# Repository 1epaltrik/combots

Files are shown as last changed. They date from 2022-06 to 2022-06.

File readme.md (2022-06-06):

<p style="text-align: center;"><h1> Έξυπνο σύστημα κομποστοποίησης </h1></p>
<br>
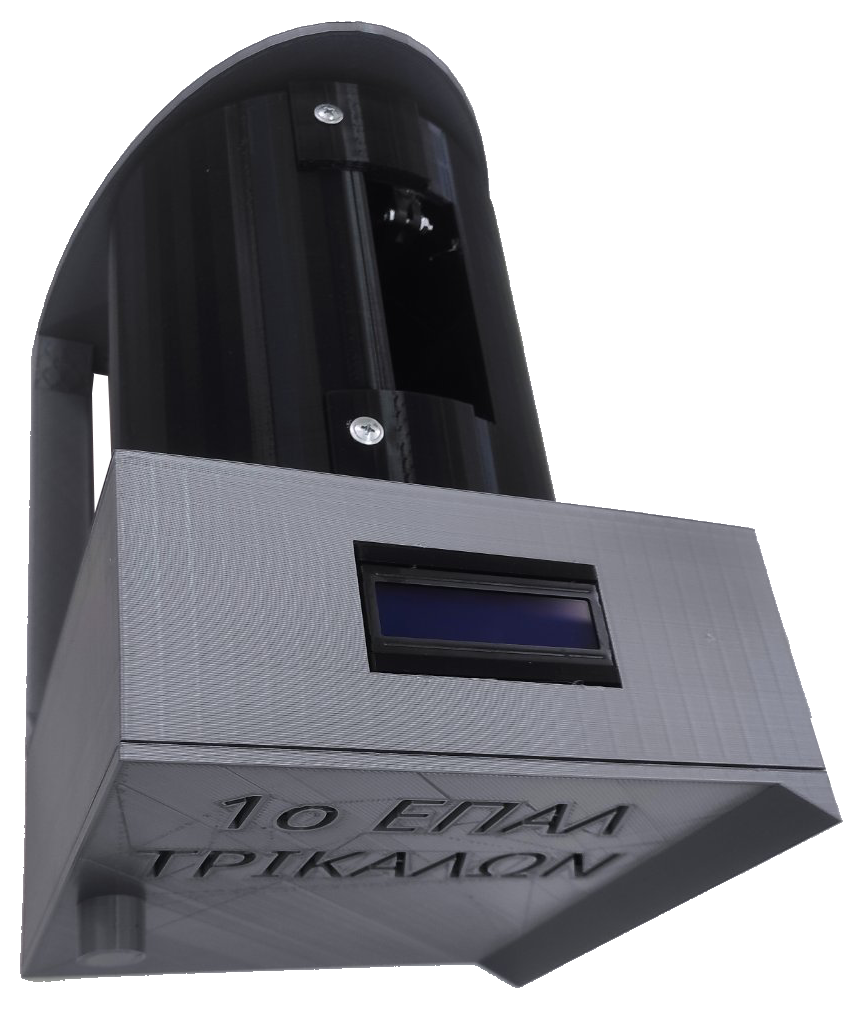
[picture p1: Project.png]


<p style="text-align: justify;">Είμαστε η ομάδα ComBots από το 1ο ΕΠΑΛ Τρικάλων.</p>
<p style="text-align: justify;">Αρχικά μελετήσαμε την υπάρχουσα κατάσταση γύρω από την κομποστοποίηση αντλώντας πληροφορίες κυρίως από το διαδίκτυο αλλά και από βιβλία. Διαπιστώσαμε ότι ένα σύστημα κομποστοποίησης μπορεί να ελαχιστοποιήσει ή και να μηδενίσει τα απόβλητα σε όλα τα στάδια παραγωγής, αλλά και μετά το τέλος του κύκλου ζωής των προϊόντων. Βασική επιδίωξη είναι η ενθάρρυνση χρήσης δευτερογενών υλικών και αποβλήτων ως παραγωγικών πόρων και χρήσιμων υλικών προσδίδοντας τη διάσταση της βιωσιμότητας στο παραγωγικό μοντέλο.</p>
<p style="text-align: justify;">Πριν ξεκινήσουμε την υλοποίηση του έργου ασχοληθήκαμε με τις αρχές και τις πρακτικές της Επιστήμης των Πολιτών. Από τη στιγμή που έπεσε η ιδέα της κομποστοποίησης κάναμε την έρευνα που αναφέραμε και δημιουργήσαμε ένα ερωτηματολόγιο σχετικό με την κυκλική οικονομία και την κομποστοποίηση για τη συμπεριφορά και τις απόψεις μαθητών και πολιτών της πόλης μας. Σημαντικότερα αποτελέσματα που εξάγουμε από το ερωτηματολόγιό αναφέρονται στο βίντεο που ακολουθεί.</p>
<p style="text-align: justify;">Η κομποστοποίηση αποτελεί ένα μέρος της Κυκλικής Οικονομίας και βοηθάει στην αντιμετώπιση του φαινομένου της  Κλιματικής Αλλαγής. Η ενθάρρυνση χρήσης συστημάτων κομποστοποίησης από κοινότητες, Δήμους, Περιφέρειες, Ιδιωτικούς Φορείς και γενικότερα των πολιτών κρίνεται απαραίτητη, ειδικά στην εποχή που διανύουμε.</p>
<p style="text-align: justify;">Δημιουργήσαμε ένα Έξυπνο σύστημα κομποστοποίησης, το οποίο μέσω αισθητήρων θα καταγράφει στο εσωτερικό του:</p>

<ol style="text-align: justify;">
 	<li>Υγρασία μείγματος κομπόστ</li>
 	<li>Υγρασία αέρα</li>
 	<li>Θερμοκρασία αέρα</li>
 	<li>Επίπεδα μεθανίου</li>
</ol>
<p style="text-align: justify;">Ανάλογα με τις τιμές ενεργοποιείται ένα σύστημα αερισμού, ένα σύστημα αύξησης της υγρασίας στο εσωτερικό και ένα μοτέρ που μετακινεί το περιεχόμενο του κάδου κομποστοποίησης. Όλες αυτές οι τιμές εμφανίζονται στην οθόνη που υπάρχει στην κατασκευή μας.</p>
<p style="text-align: justify;">Αντίστοιχο σύστημα έξυπνης κομποστοποίησης δεν βρήκαμε ούτε στην ελληνική, ούτε στην ξένη αγορά. Για την υλοποίησή του χρησιμοποιήσαμε Ανοιχτές Τεχνολογίες μέσω μιας διάταξης Arduino, το Διαδίκτυο των πραγμάτων και τρισδιάστατη εκτύπωση.</p>
<p style="text-align: justify;">Τα υλικά που χρησιμοποιήσαμε ήταν:</p>

<ul style="text-align: justify;">
 	<li>Ένα Funduino Mega2560</li>
 	<li>Ένα Breadboard</li>
 	<li>Μία Οθόνη LCD - RGB Ι2C</li>
 	<li>Έναν αισθητήρα Θερμοκρασίας/Υγρασίας/Βαρομετρικής Πίεσης I2C BME280</li>
 	<li>Έναν αισθητήρα Μεθανίου CNG - MQ-4</li>
 	<li>Ένα Relay 2 θέσεων</li>
 	<li>Μία αντλία νερού</li>
 	<li>Έναν ανεμιστήρα</li>
 	<li>Έναν βηματικό Κινητήρα 4.5kg με Οδηγό A4988</li>
 	<li>Καλώδια για τη διασύνδεση όλων αυτών και</li>
 	<li>Νήμα για την τρισδιάστατη εκτύπωση</li>
</ul>
<p style="text-align: justify;">Το κόστος όλων αυτών ανήλθε στα €150.</p>
<p style="text-align: justify;">H σχεδίαση του κυκλώματος έγινε λαμβάνοντας υπόψη όσα ανακαλύφθηκαν από την έρευνα που πραγματοποιήσαμε. Στην αρχή είδαμε τον κάθε αισθητήρα και σύστημα ενεργοποίησης, αλλά στο τέλος τα συνθέσαμε όλα μαζί. Η έρευνά μας, τα σχέδια των κυκλωμάτων και ο κώδικας για την υλοποίηση του έργου μας είναι διαθέσιμα στο github (<a href="https://github.com/1epaltrik/combots">https://github.com/1epaltrik/combots</a>).</p>
<p style="text-align: left;">Tο βίντεο με την παρουσίαση του έργου, από την αρχή μέχρι και την ολοκλήρωσή του θα το βρείτε στην ιστοσελίδα <a href="https://youtu.be/cvGBoXvN4oI">https://youtu.be/cvGBoXvN4oI</a></p>
<p style="text-align: justify;">Στόχος μας μετά τον διαγωνισμό είναι να παρουσιάσουμε την ιδέα μας στον Δήμο που κατοικούμε, προτείνοντας να τοποθετηθούν στην πόλη κάδοι κομποστοποίησης μεγαλύτερης κλίμακας που θα χρησιμοποιούν τις τεχνολογίες που ανακαλύψαμε για τη συμβολή της έξυπνης πόλης μας στην κυκλική οικονομία.</p>
&nbsp;

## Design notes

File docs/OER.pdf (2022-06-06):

## Έξυπνο σύστημα κομποστοποίησης 1ο ΕΠΑΛ Τρικάλων

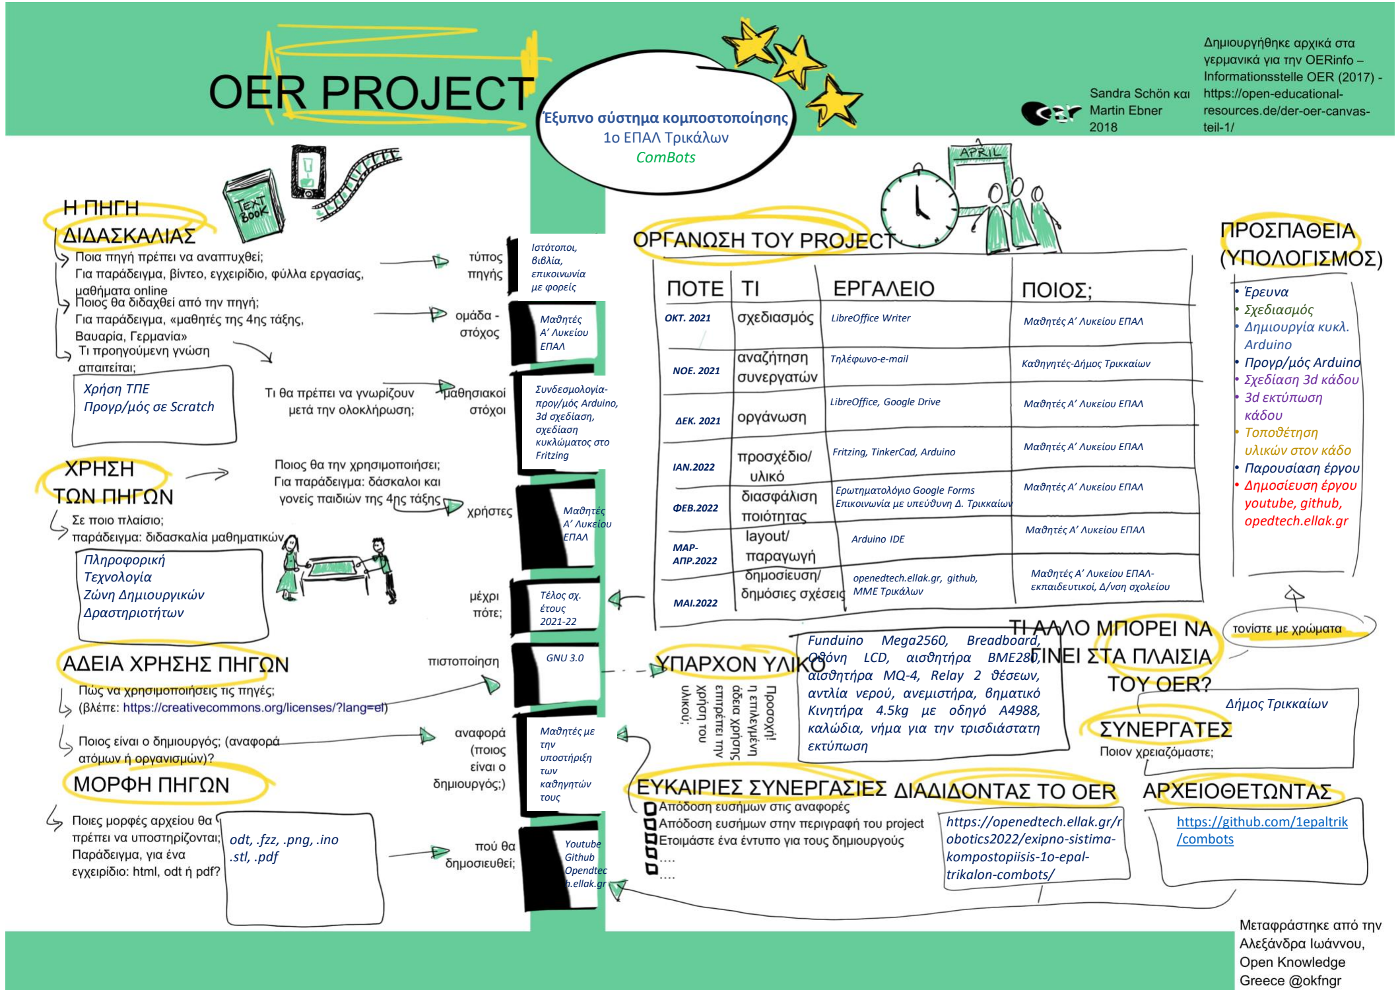
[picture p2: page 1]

## Χρήση ΤΠΕ Προγρ/μός σε Scratch

## Πληροφορική Τεχνολογία Ζώνη Δημιουργικών Δραστηριοτήτων

## odt, .fzz, .png, .ino .stl, .pdf

## https://openedtech.ellak.gr/r obotics2022/exipno-sistimakompostopiisis-1o-epaltrikalon-combots/

## https://github.com/1epaltrik /combots (https://github.com/1epaltrik/combots)

## Δήμος Τρικκαίων

## - Έρευνα - Σχεδιασμός

- Δημιουργία κυκλ.

## Arduino - Προγρ/μός Arduino - Σχεδίαση 3d κάδου - 3d εκτύπωση κάδου - Τοποθέτηση υλικών στον κάδο - Παρουσίαση έργου - Δημοσίευση έργου

youtube, github,

## opedtech.ellak.gr

## ComBots

Ιστότοποι,
βιβλία,
επικοινωνία
με φορείς

Μαθητές
Α’ Λυκείου
ΕΠΑΛ

Συνδεσμολογίαπρογ/μός Arduino,
3d σχεδίαση,
σχεδίαση
κυκλώματος στο
Fritzing

Μαθητές
Α’ Λυκείου
ΕΠΑΛ

Τέλος σχ.
έτους
2021-22

GNU 3.0

Μαθητές με
την
υποστήριξη
των
καθηγητών
τους

Youtube
Github
Opendtec
h.ellak.gr
Funduino | Mega2560, | Breadboard,
Οθόνη LCD, αισθητήρα BME280, αισθητήρα MQ-4, Relay 2 θέσεων,

## αντλία νερού, ανεμιστήρα, βηματικό

Κινητήρα 4.5kg με oδηγό A4988,

## καλώδια, νήμα για την τρισδιάστατη εκτύπωση

ΟΚΤ. 2021 | LibreOffice Writer

ΝΟΕ. 2021

ΔΕΚ. 2021

ΙΑΝ.2022

ΦΕΒ.2022

ΜΑΡ-ΑΠΡ.2022

ΜΑΙ.2022

Μαθητές Α’ Λυκείου ΕΠΑΛ

Fritzing, TinkerCad, Arduino

Τηλέφωνο-e-mail | Καθηγητές-Δήμος Τρικκαίων

Μαθητές Α’ Λυκείου ΕΠΑΛ

Μαθητές Α’ Λυκείου ΕΠΑΛ

Μαθητές Α’ Λυκείου ΕΠΑΛ

Μαθητές Α’ Λυκείου ΕΠΑΛ

Μαθητές Α’ Λυκείου ΕΠΑΛεκπαιδευτικοί, Δ/νση σχολείου

Arduino IDE

Ερωτηματολόγιο Google Forms Επικοινωνία με υπεύθυνη Δ. Τρικκαίων

LibreOffice, Google Drive

openedtech.ellak.gr, github, ΜΜΕ Τρικάλων

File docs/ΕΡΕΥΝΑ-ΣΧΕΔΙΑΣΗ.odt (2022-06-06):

Έρευνα

Σημαντικές έννοιες

Κυκλική οικονομία είναι η επιμήκυνση του κύκλου ζωής των προϊόντων, με παράλληλη εξοικονόμηση μη ανανεώσιμων φυσικών πόρων, μέσω της μείωσης, επαναχρησιμοποίησης, ανακύκλωσης και ανάκτησης πρώτων υλών, ενέργειας και αποβλήτων.

Η κομποστοποίηση είναι μια φυσική διαδικασία η οποία μετατρέπει τα οργανικά υλικά σε μια πλούσια σκούρα ουσία. Αυτή η ουσία λέγεται κομπόστ ή χούμους ή εδαφοβελτιωτικό. Η κομποστοποίηση είναι ένας πολύ άμεσος και σημαντικός τρόπος ανακύκλωσης. Έχει υπολογιστεί ότι το 35% των οικιακών απορριμμάτων μπορούν να κομποστοποιηθούν.

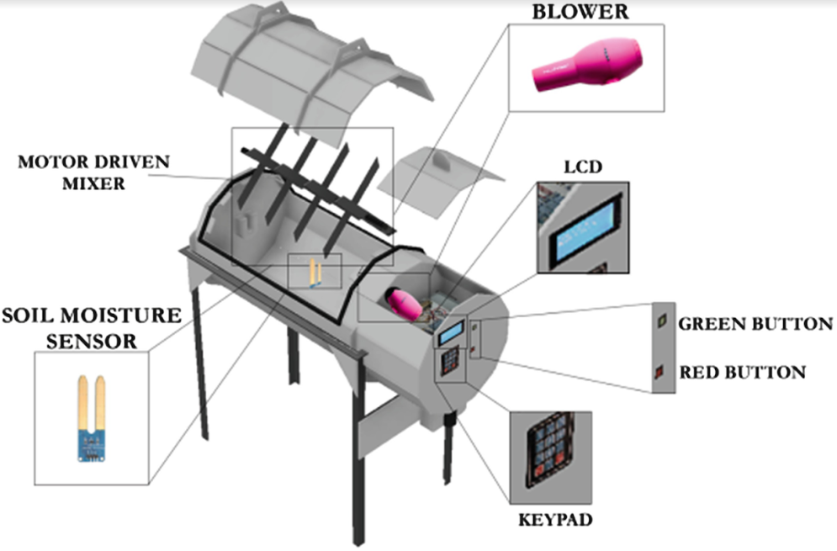
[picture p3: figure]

Προϋποθέσεις - υλικά κομποστοποίησης

Τα μόνα υλικά που απαιτούνται για την παραγωγή οικιακού κομπόστ συνοψίζονται στα παρακάτω:

- Ειδικός κάδος κομποστοποίησης (με λίγους ή και καθόλου γαιοσκώληκες)
- Λίγο χώμα κήπου ή και καθόλου
- Εργαλεία (ειδικό εργαλείο για ανακάτεμα και αερισμό, σκαλιστήρι, ποτιστήρι)
- Μικρό καδάκι κουζίνας για τη συλλογή των υλικών στην κουζίνα

H λιπασματοποίηση είναι ευεργετική για το περιβάλλον. Όταν τα απορρίμματα τροφίμων ρίχνονται στον κάδο απορριμμάτων και αποστέλλονται στον χώρο υγειονομικής ταφής, απελευθερώνεται τοξικό αέριο μεθάνιο. Για παράδειγμα, εάν αποστέλλονται 180 κιλά απόβλητα τροφίμων στον χώρο υγειονομικής ταφής, παράγονται 15.3 κιλά αέριο μεθανίου.

Το αέριο μεθάνιο είναι περίπου 28 φορές πιο ισχυρό από το διοξείδιο του άνθρακα όταν πρόκειται για τη θέρμανση της Γης σε κλίμακα 100 ετών και περισσότερο από 80 φορές πιο ισχυρό για 20 χρόνια.

Αν και δεν υπάρχει πολύ μεθάνιο στον αέρα, λόγω της χημικής του σύστασης, είναι πολύ αποτελεσματικό στην παγίδευση της θερμότητας. Οι επιστήμονες πιστεύουν ότι περίπου το 60% του μεθανίου στην ατμόσφαιρα προέρχεται από πηγές που σχετίζονται με τον άνθρωπο. Η κομποστοποίηση σταματά (ή μειώνει σημαντικά) την παραγωγή μεθανίου.

Σε τί στοχεύει:

Κεντρικός στόχος ενός συστήματος κομποστοποίησης είναι η παραγωγή προϊόντων με λιγότερους και πιο «πράσινους πόρους». Δηλαδή με ελαχιστοποίηση ή και μηδενισμό των αποβλήτων σε όλα τα στάδια παραγωγής, αλλά και μετά το τέλος του κύκλου ζωής των προϊόντων. Επιδιώκει και ενθαρρύνει την χρήση δευτερογενών υλικών και αποβλήτων ως παραγωγικών πόρων και χρήσιμων υλικών, προσδίδοντας τη διάσταση της βιωσιμότητας στο παραγωγικό μοντέλο. Τα οφέλη που προκύπτουν από τη διαδικασία της κομποστοποίησης είναι:

- μείωση των εκπομπών του θερμοκηπίου από 2% έως 4%,
- εξοικονόμηση 600 δισ. ευρώ για τις επιχειρήσεις (ισοδυναμεί με το 6%-8% του κύκλου εργασιών τους),
- δημιουργία άνω των 2 εκατομμυρίων θέσεων εργασίας,
- ανάπτυξη έως 6% με ταυτόχρονη εξοικονόμηση πόρων – σήμερα, για παράδειγμα, το 80% των προϊόντων μετατρέπονται σε απόβλητα μέσα στους πρώτους 6 μήνες από τη διάθεσή τους στην αγορά.

Το Ινστιτούτο Κυκλικής Οικονομίας και Κλιματικής Αλλαγής προωθεί κυκλικές και βιώσιμες πρακτικές, την κλιματική και περιβαλλοντική διπλωματία ώστε να ενσωματώσει την Κυκλική Οικονομία σε όλους τους τομείς τοπικών, εθνικών αλλά και Ευρωπαϊκών πολιτικών. Στόχος του Ινστιτούτου είναι η προσαρμογή των τοπικών Κυβερνήσεων, Περιφερειών, Δήμων, Ιδιωτικών Φορέων και άλλων ενδιαφερομένων στο νέο οικονομικό μοντέλο, δημιουργία νέων επενδύσεων και νέων θέσεων εργασίας υψηλής εξειδίκευσης.

Ο ρόλος του Ινστιτούτου είναι να προσφέρει τεχνική βοήθεια, να προωθεί καινοτόμες «κυκλικές» δράσεις και καλές πρακτικές, να παρέχει περιβαλλοντική συμβουλευτική, να διαχειρίζεται έργα, συγχρηματοδοτούμενα από την ΕΕ καθώς και ιδιωτικές επενδύσεις εστιασμένες στην πράσινη και μπλε ανάπτυξη, να παρέχει περιβαλλοντικές νομικές συστάσεις ή νομική εκπροσώπηση και βοήθεια σε όλα τα περιβαλλοντικά θέματα, σε περιπτώσεις περιβαλλοντικών παραβιάσεων ή κυρώσεων.

Σε αυτό το πλαίσιο, η Ευρωπαϊκή Τράπεζα Επενδύσεων, η οποία είναι πλέον η κλιματική τράπεζα της Ευρώπης, στηρίζει τις επενδύσεις που θα χρειαστούν για την επίτευξη των κλιματικών στόχων και τη μετάβαση σε μια οικονομία ουδέτερου αποτυπώματος άνθρακα. Αντίστοιχα, το Ταμείο Δίκαιης Μετάβασης θα βοηθήσει περιοχές ιδιαίτερα εξαρτημένες από τον άνθρακα να στραφούν σε νέες μορφές οικονομικής δραστηριότητας, καθώς είναι σημαντικό στην πορεία προς μια κλιματικά ουδέτερη Ευρώπη έως το 2050 να συμμετέχουν όλες οι περιοχές.

Επομένως, η Ευρώπη, άρα και η Ελλάδα, μπορούν να αναδυθούν ισχυρότερες από την πανδημία μέσα από μία πράσινη ανάκαμψη, επενδύοντας στην κυκλική οικονομία, την εξοικονόμηση ενέργειας, τις ανανεώσιμες πηγές ενέργειας, τις βιώσιμες μεταφορές και την καθαρή τεχνολογία, δημιουργώντας πράσινες θέσεις εργασίας.

Επικοινωνία με φορείς

Πραγματοποιήθηκε τηλεδιάσκεψη με την ειδικό συνεργάτη του Δήμο Τρικκαίων κυρία Κωνσταντίνα Ζαχαρή.

Οι μαθητές ενημερώθηκαν για την επικείμενη εγκατάσταση ολοκληρωμένου συστήματος κυκλικής οικονομίας για αστικούς λαχανόκηπους στα Τρίκαλα. Ένα πρόγραμμα που έχει ως στόχο τη συμμετοχή των πολιτών στην προσπάθεια για μείωση του περιβαλλοντικού αποτυπώματος. Το συγκεκριμένο σύστημα αποτελείται από 4 μέρη: α) τον ενσωματωμένο κάδο κομποστοποίησης, β) τον συλλέκτη βρόχινου νερού, γ) τον ενσωματωμένο χώρο φύτευσης των καλλιεργειών και δ) το έξυπνο σύστημα διαχείρισης κήπων και κομπόστ.

Με τη χρήση του συστήματος αυτού ο Δήμος Τρικκαίων και οι δημότες του θα έχουν σημαντικά οφέλη, όπως:

- Μείωση χρησιμοποιούμενης ποσότητας νερού από το δίκτυο υδροδότησης
- Μείωση χρήσης λιπάσματος εμπορίου
- Μείωση χρήσης νερού για παραγωγή
- Αύξηση της παραγόμενης ποσότητας λαχανικών
- Μείωση κόστους παραγωγής
- Μείωση ποσότητας απορριμμάτων

Μετά από τη σημαντική αυτή ενημέρωση οι μαθητές αποφάσισαν να δημιουργήσουν ένα δικό τους σύστημα για έξυπνη κομποστοποίηση για να βοηθήσουν στην εφαρμογή κυκλικής οικονομίας στον Δήμο μας.

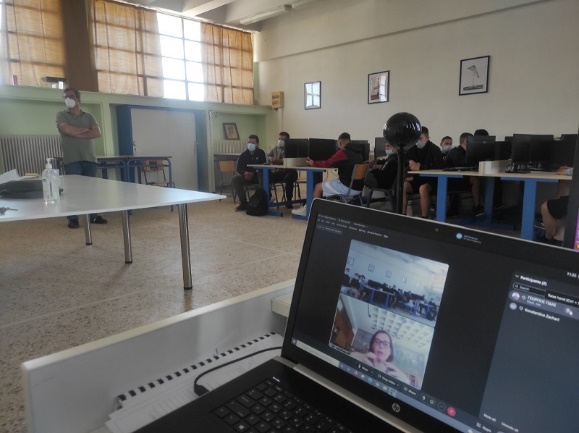
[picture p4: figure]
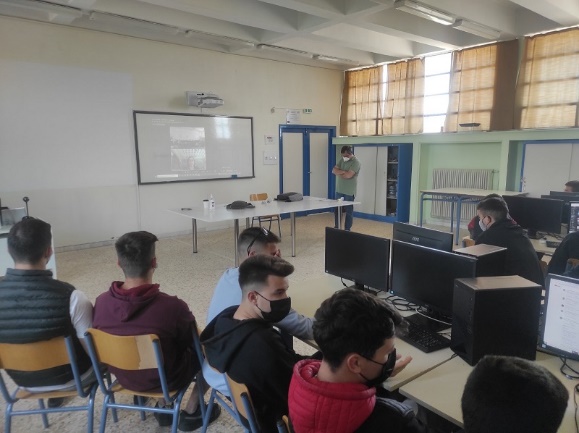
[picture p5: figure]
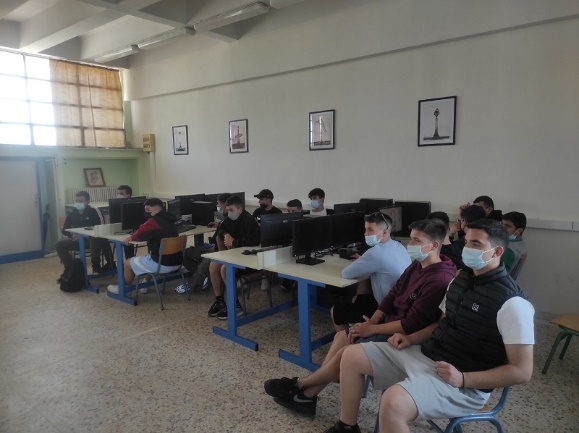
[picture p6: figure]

Ερωτηματολόγια

Πριν ξεκινήσουμε την υλοποίηση του έργου ασχοληθήκαμε με τις αρχές και τις πρακτικές της Επιστήμης των Πολιτών. Από τη στιγμή που έπεσε η ιδέα της κομποστοποίησης κάναμε την έρευνα που αναφέραμε και δημιουργήσαμε ένα ερωτηματολόγιο σχετικό με την κυκλική οικονομία και την κομποστοποίηση για τη συμπεριφορά και τις απόψεις μαθητών και πολιτών της πόλης μας.

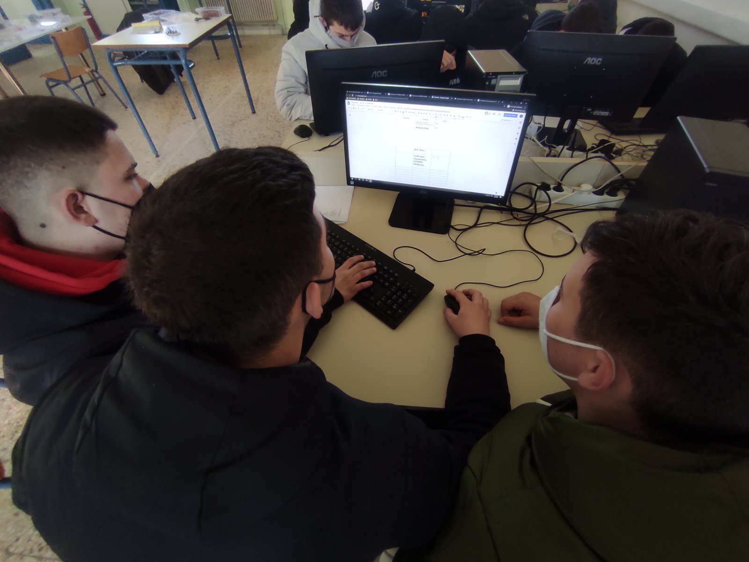
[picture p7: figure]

Τα σημαντικότερα αποτελέσματα που προκύπτουν από το ερωτηματολόγιο αναφέρονται στο βίντεο που βρίσκεται στην ιστοσελίδα https://youtu.be/cvGBoXvN4oI. Αναλυτικά οι απαντήσεις στα ερωτηματολόγια φαίνονται στις εικόνες που ακολουθούν.

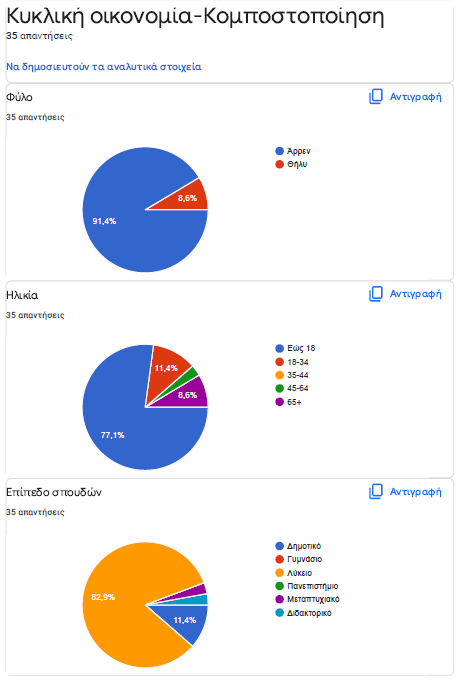
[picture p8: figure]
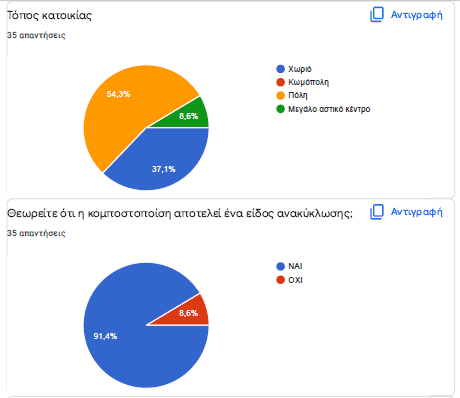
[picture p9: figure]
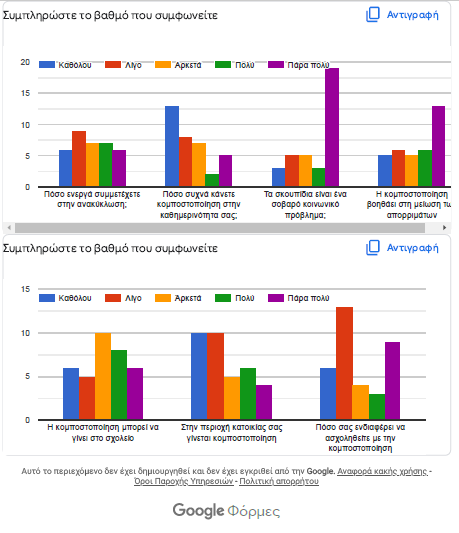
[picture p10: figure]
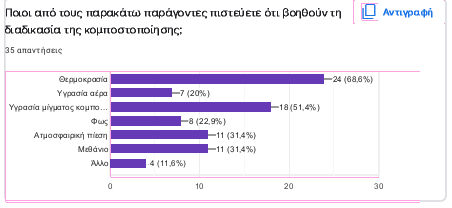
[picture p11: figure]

Η κομποστοποίηση αποτελεί ένα μέρος της Κυκλικής Οικονομίας και βοηθάει στην αντιμετώπιση του φαινομένου της Κλιματικής Αλλαγής. Η ενθάρρυνση χρήσης συστημάτων κομποστοποίησης από κοινότητες, Δήμους, Περιφέρειες, Ιδιωτικούς Φορείς και γενικότερα των πολιτών κρίνεται απαραίτητη, ειδικά στην εποχή που διανύουμε.

ΣΧΕΔΙΑΣΗ

Αρχικά μελετήσαμε την υπάρχουσα κατάσταση γύρω από την κομποστοποίηση αντλώντας πληροφορίες από το διαδίκτυο και από βιβλία καθώς και επικοινωνία με αρμόδιους φορείς. Διαπιστώσαμε ότι ένα σύστημα κομποστοποίησης μπορεί να ελαχιστοποιήσει ή και να μηδενίσει τα απόβλητα σε όλα τα στάδια παραγωγής, αλλά και μετά το τέλος του κύκλου ζωής των προϊόντων. Βασική επιδίωξη είναι η ενθάρρυνση χρήσης δευτερογενών υλικών και αποβλήτων ως παραγωγικών πόρων και χρήσιμων υλικών προσδίδοντας τη διάσταση της βιωσιμότητας στο παραγωγικό μοντέλο.

Δημιουργήσαμε ένα Έξυπνο σύστημα κομποστοποίησης, το οποίο μέσω αισθητήρων θα καταγράφει στο εσωτερικό του:

1. Υγρασία μείγματος κομπόστ
2. Υγρασία αέρα
3. Θερμοκρασία αέρα
4. Επίπεδα μεθανίου

Ανάλογα με τις τιμές ενεργοποιείται ένα σύστημα αερισμού, ένα σύστημα αύξησης της υγρασίας στο εσωτερικό και ένα μοτέρ που μετακινεί το περιεχόμενο του κάδου κομποστοποίησης. Όλες αυτές οι τιμές εμφανίζονται στην οθόνη που υπάρχει στην κατασκευή μας.

Αντίστοιχο σύστημα έξυπνης κομποστοποίησης δεν βρήκαμε ούτε στην ελληνική, ούτε στην ξένη αγορά. Για την υλοποίησή του χρησιμοποιήσαμε Ανοιχτές Τεχνολογίες μέσω μιας διάταξης Arduino, το Διαδίκτυο των πραγμάτων και τρισδιάστατη εκτύπωση.

Τα υλικά που χρησιμοποιήσαμε ήταν:

- Ένα Funduino Mega2560
- Ένα Breadboard
- Μία Οθόνη LCD - RGB Ι2C
- Έναν αισθητήρα Θερμοκρασίας/Υγρασίας/Βαρομετρικής Πίεσης I2C BME280
- Έναν αισθητήρα Μεθανίου CNG - MQ-4
- Ένα Relay 2 θέσεων
- Μία αντλία νερού
- Έναν ανεμιστήρα
- Έναν βηματικό Κινητήρα 4.5kg με Οδηγό A4988
- Καλώδια για τη διασύνδεση όλων αυτών και
- Νήμα για την τρισδιάστατη εκτύπωση

Το κόστος όλων αυτών ανήλθε στα €150.

Η διάταξη που είχε το κύκλωμα που δημιουργήσαμε φαίνεται στην παρακάτω εικόνα

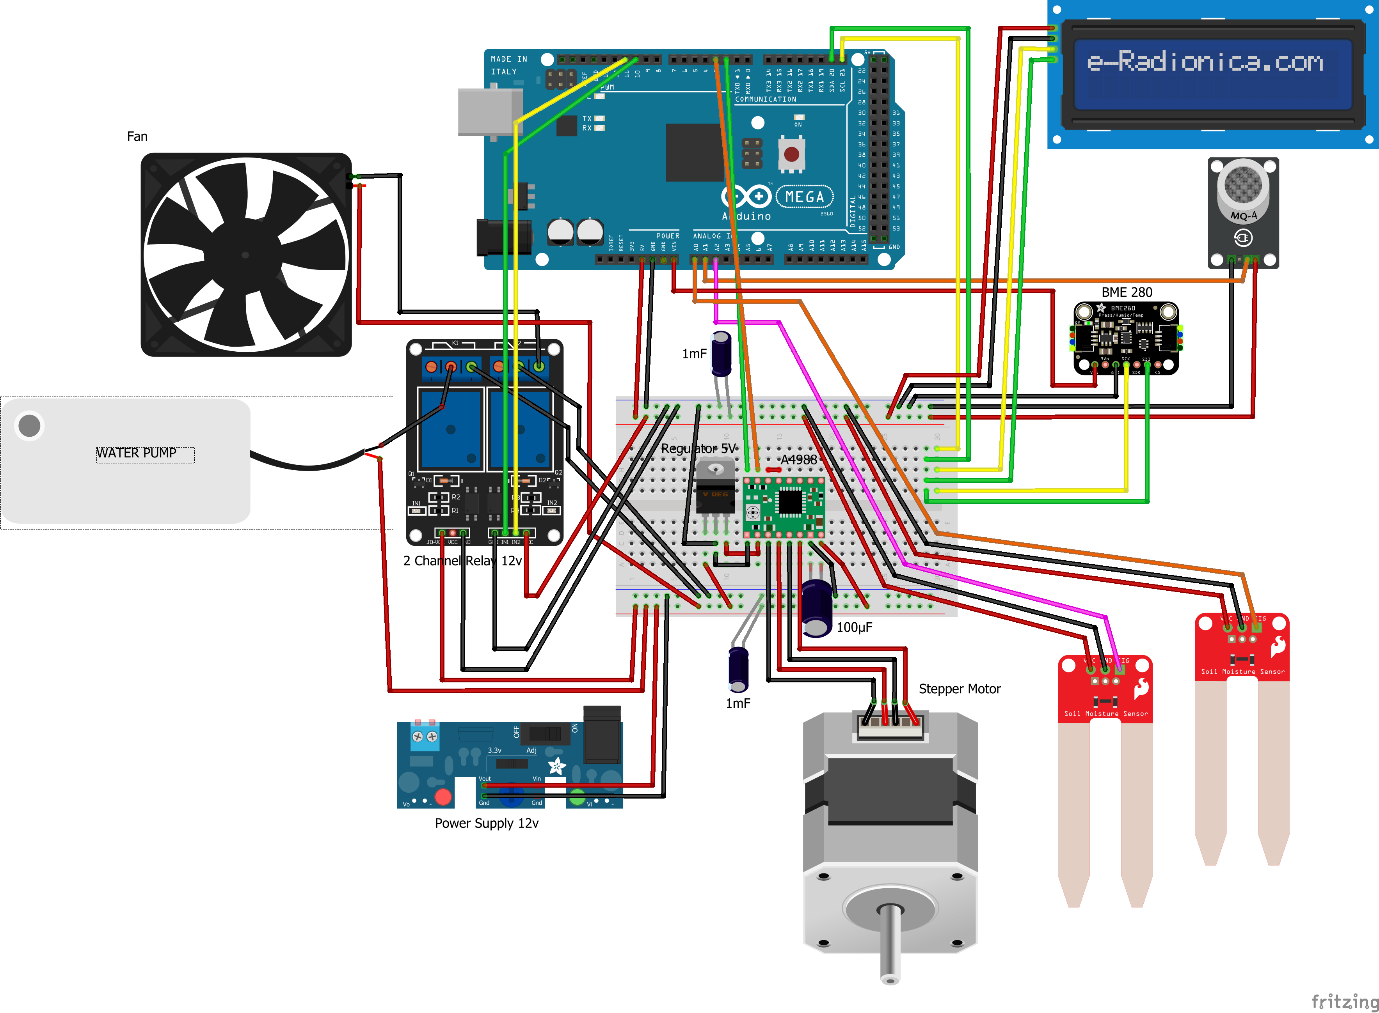
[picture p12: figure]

H σχεδίαση του κυκλώματος έγινε λαμβάνοντας υπόψη όσα ανακαλύφθηκαν από την έρευνα που πραγματοποιήσαμε. Στην αρχή είδαμε τον κάθε αισθητήρα και σύστημα ενεργοποίησης, αλλά στο τέλος τα συνθέσαμε όλα μαζί.

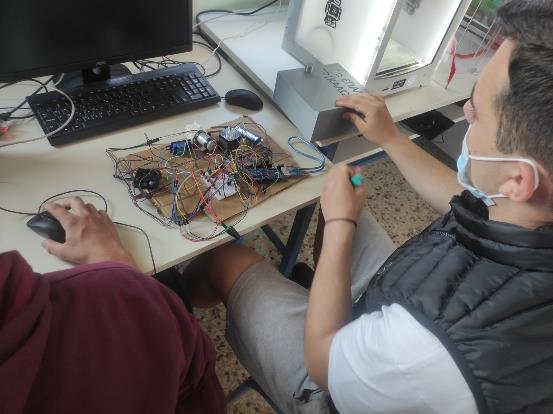
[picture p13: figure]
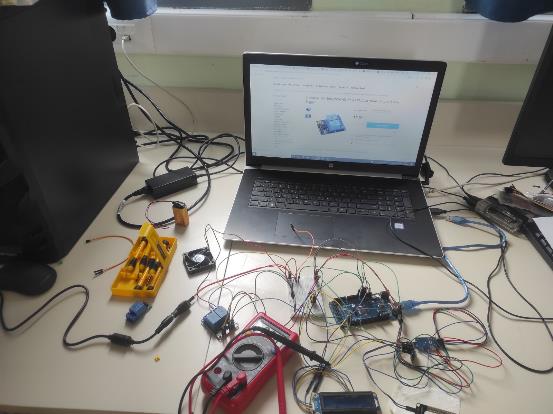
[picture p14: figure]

Όλο το κύκλωμα τοποθετήθηκε στο τέλος σε έναν κάδο κομποστοποίησης που σχεδιάσαμε στο TinkerCad και εκτυπώσαμε στον 3d εκτυπωτή του σχολείου μας

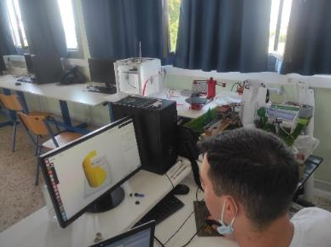
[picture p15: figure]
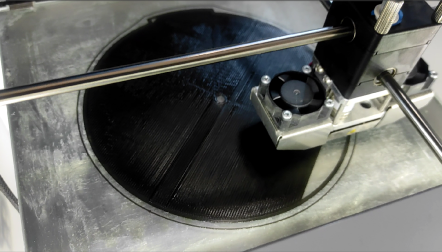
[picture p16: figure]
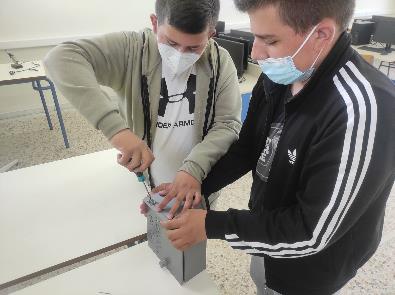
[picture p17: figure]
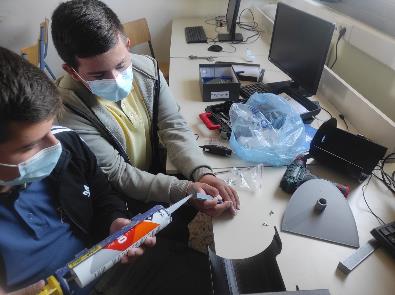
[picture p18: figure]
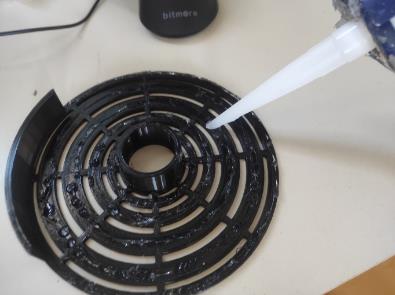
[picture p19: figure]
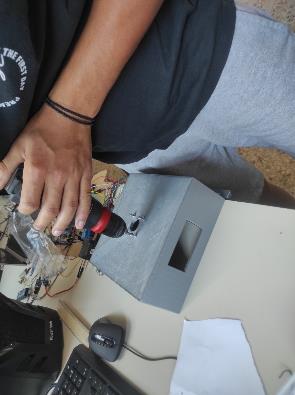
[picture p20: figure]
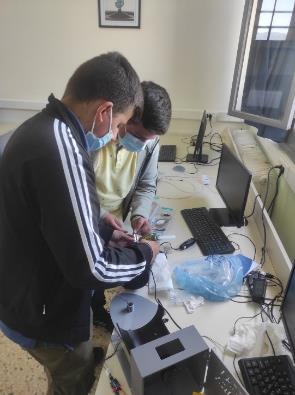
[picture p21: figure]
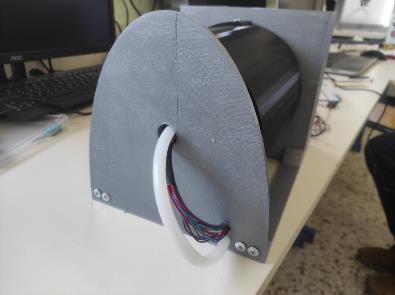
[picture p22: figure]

`

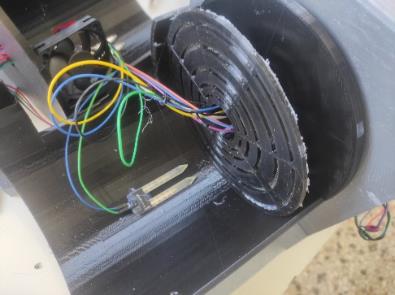
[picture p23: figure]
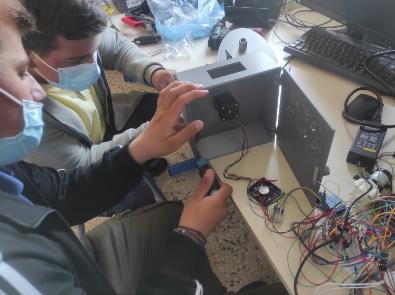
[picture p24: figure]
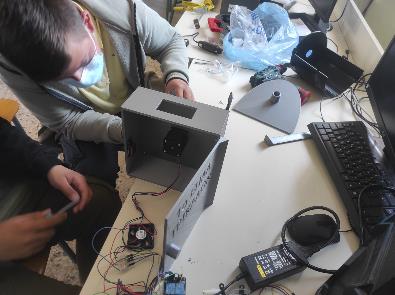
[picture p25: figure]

Η έρευνά μας, τα σχέδια των κυκλωμάτων και ο κώδικας για την υλοποίηση του έργου μας είναι διαθέσιμα στο github (https://github.com/1epaltrik/combots).


ΠΗΓΕΣ

http://www.ecorec.gr/ecorec/index.php?option=com_content&view=category&id=64&Itemid=537&lang=en

https://create.arduino.cc/projecthub/mjrobot/iot-made-easy-w-uno-esp-01-thingspeak-mit-app-inventor-da6a50

https://el.wikipedia.org/w/index.php?title=Κομποστοποίηση&veaction=edit&section=3

https://github.com/1epaltrik/climabots

https://github.com/1epaltrik/virusbots

https://lastminuteengineers.com/bme280-arduino-tutorial/

https://trikalacity.gr/kykliki-oikonomia-kai-kompostopoiisi-se-lachanokipoys-spition-sta-trikala/

https://www.bestprice.gr/blog/163/kompostopoiisi-sto-spiti

https://www.researchgate.net/publication/315870621_Automation_of_plastic_metal_and_glass_waste_materials_segregation_using_arduino_in_scrap_industry

https://www.slideshare.net/georgemarkatatos/ss-48978059

Γίδας, Γ., Μαντζάνας, Ε. (2021). Εφαρμογές Arduino στο σχολικό εργαστήριο για το περιβάλλον. Τρίκαλα: 1ο ΕΠΑΛ Τρικάλων.

1ο ΕΠΑΛ Τρικάλων (ComBots) Έξυπνο σύστημα κομποστοποίησης

4ος Πανελλήνιος Διαγωνισμός Ανοιχτών Τεχνολογιών στην Εκπαίδευση 2

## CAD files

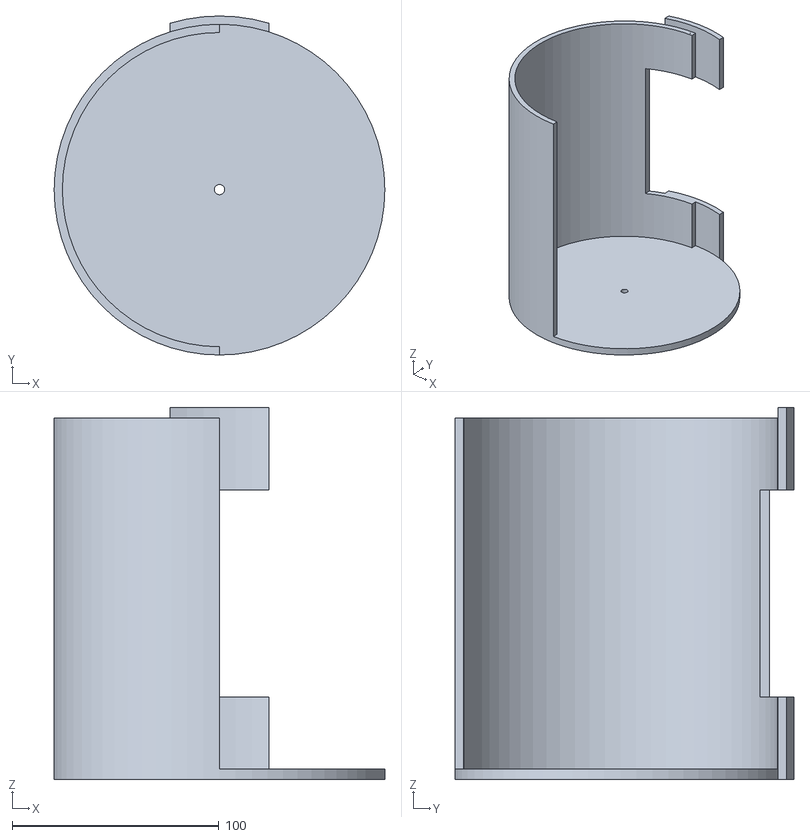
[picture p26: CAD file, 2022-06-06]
code/stl/kadosComp2.stl
160.0 x 164.0 x 180.0

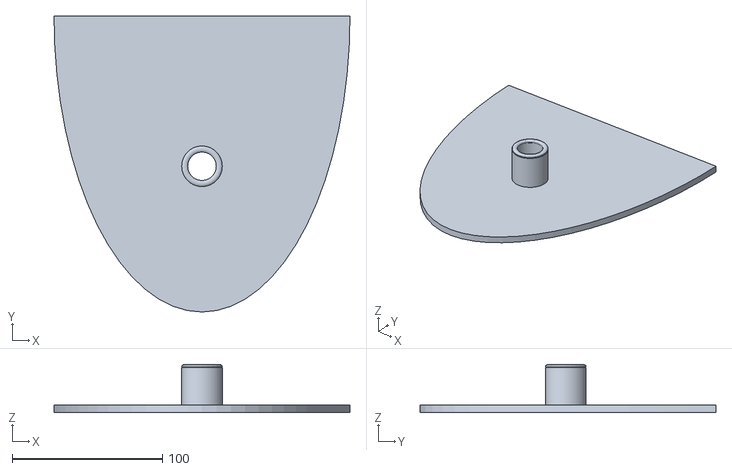
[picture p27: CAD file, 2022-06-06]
code/stl/support.stl
197.0 x 197.0 x 32.0

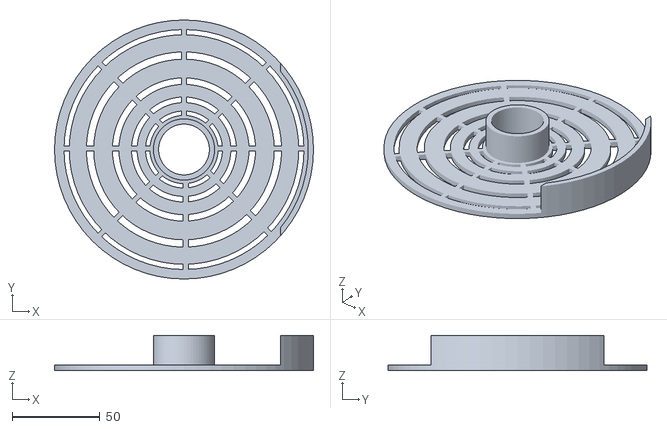
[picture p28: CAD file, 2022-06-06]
code/stl/sensor_divider.stl
148.0 x 148.0 x 20.0

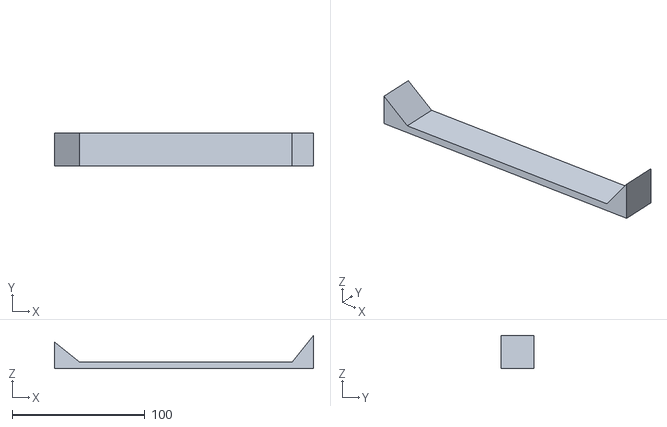
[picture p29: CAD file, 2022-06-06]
code/stl/bracket.stl
195.0 x 25.0 x 25.0

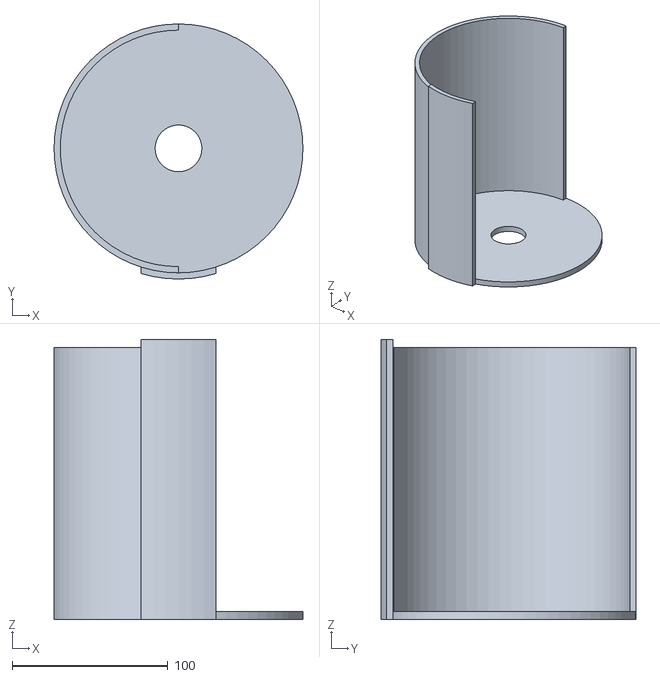
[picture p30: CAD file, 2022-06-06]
code/stl/kadosComp1.stl
160.0 x 164.0 x 180.0

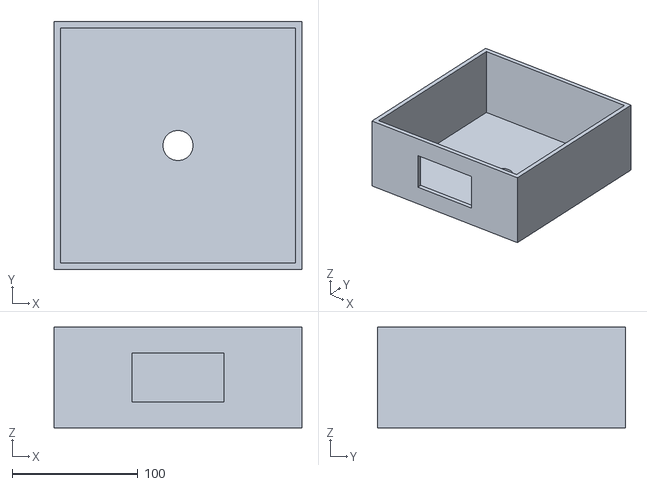
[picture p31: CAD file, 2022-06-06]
code/stl/comp_case.stl
197.0 x 197.0 x 80.0

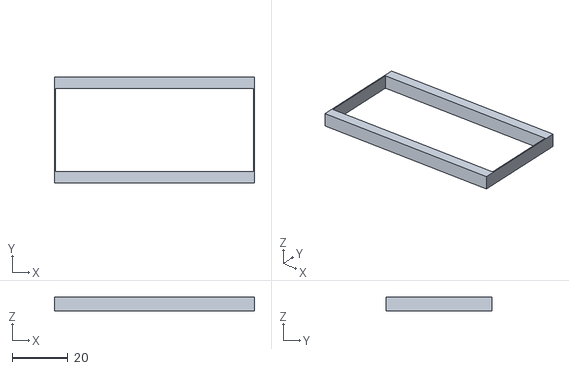
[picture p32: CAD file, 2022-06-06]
code/stl/lcd_frame.stl
72.0 x 38.0 x 5.00

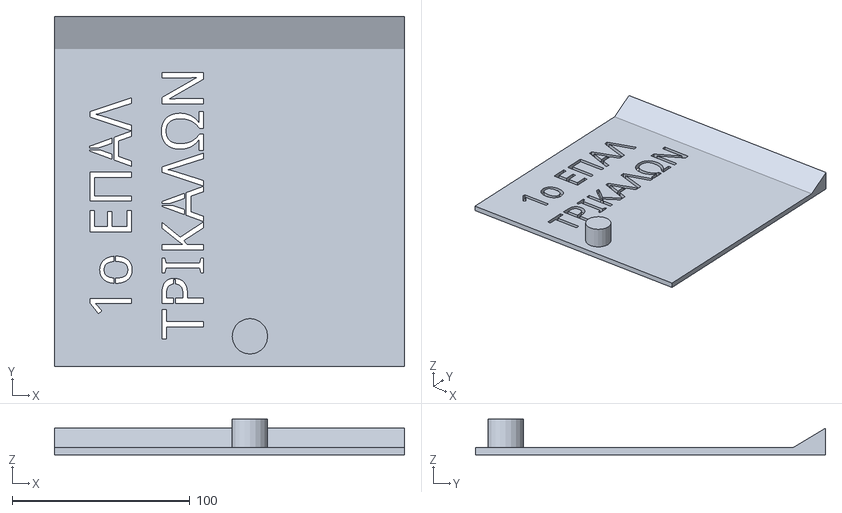
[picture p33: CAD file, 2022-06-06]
code/stl/comp_casecover.stl
197.0 x 197.0 x 20.0

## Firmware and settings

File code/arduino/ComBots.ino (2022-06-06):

/******************************************************************
 * Κάδος κομποστοποίησης
 * 1ο ΕΠΑΛ Τρικάλων - Ομάδα ComBots
 * 4ος Πανελλήνιος Διαγωνισμός Ανοιχτών Τεχνολογιών στην Εκπαίδευση
 ******************************************************************/

// βιβλιοθήκες
#include "DFRobot_RGBLCD1602.h"
#include <Wire.h>
#include <SPI.h>
#include <Adafruit_Sensor.h>
#include <Adafruit_BME280.h>

// θύρες εισόδου-εξόδου
const int switchPin = 4;  // θύρα σύνδεσης του διακόπτη εύρεσης της αρχικής θέσης του κάδου
const int motorPin = 10;  // θύρα ελέγχου αντλίας
const int fanPin = 11;    // θύρα ελέγχου ανεμιστήρα
const int dirPin = 2;     // θύρα ελέγχου της φοράς περιστροφής του stepper motor
const int stepPin = 3;    // θύρα ελέγχου των βημάτων του stepper motor

const int stepsPerRevolution = 400;   // το μοτέρ μας κάνει 1 πλήρη περιστροφή σε 400 βήματα

int strofi = 110;             // ο αριθμός βημάτων για την περιστροφή του κάδου
int stepperSpeed = 15000;     // μεγάλη τιμή -> μικρή ταχύτητα -> μεγάλη ροπή
bool DexiaAristera = HIGH;    // LOW: προς τα δεξιά - HIGH: προς τα αριστερά

// οθόνη LCD 16x2
DFRobot_RGBLCD1602 lcd(16,2);

// αναλογικές θύρες σύνδεσης αισθητήρων
const int hygrometer = A0;    // 1ος αισθητήρας υγρασίας εδάφους
const int hygrometer2 = A2;   // 2ος αισθητήρας υγρασίας εδάφους
const int MQ4pin = A1;        // αισθητήρας μεθανίου

// οι τιμές των αισθητήρων
int value = 0;        // 1ος αισθητήρας υγρασίας εδάφους
int value2 = 0;       // 2ος αισθητήρας υγρασίας εδάφους
int methValue = 0;    // μεθάνιο
float temp = 0.0;     // θερμοκρασία
float hum = 0.0;      // υγρασία αέρα
float pressure = 0.0; // ατμοσφαιρική πίεση

// ο αισθητήρας BME280
Adafruit_BME280  bme; // I2C
//Adafruit_BME280 bme(BME_CS); // hardware SPI
//Adafruit_BME280 bme(BME_CS, BME_MOSI, BME_MISO, BME_SCK); // software SPI

void setup()
{
  // αρχικοποίηση serial monitor
  Serial.begin(9600);

  // αρχικοποίηση οθόνης LCD
  lcd.init();

  lcd.print("1o EPAL TRIKALON");
  Serial.println("1o EPAL TRIKALON");
  Serial.println("----------------");
  delay(500);
  
  // ορισμός θυρών εξόδου
  pinMode(stepPin, OUTPUT);
  pinMode(dirPin, OUTPUT);
  pinMode(motorPin, OUTPUT);
  pinMode(fanPin, OUTPUT);

  digitalWrite(fanPin, HIGH);   // ανεμιστήρας κλειστός
  digitalWrite(motorPin, HIGH); // αντλία κλειστή

  // ορισμός θυρών εισόδου
  pinMode(switchPin, INPUT_PULLUP); // ενεργοποίηση της εσωτερικής pullup αντίστασης

  // περιστροφή του κάδου στην αρχική θέση (προς τα δεξιά)
  lcd.setCursor(0, 0);
  lcd.print("PERISTROFI KADOU");
  lcd.setCursor(0, 1);
  lcd.print("STHN ARXIKH 8ESI");
  digitalWrite(dirPin, LOW);
  while( digitalRead(switchPin) == LOW )  // μέχρι να πατηθεί ο διακόπτης...
  {
    digitalWrite(stepPin, HIGH);      // ...περιστροφή κατά ένα βήμα
    delayMicroseconds(stepperSpeed);
    digitalWrite(stepPin, LOW);
    delayMicroseconds(800);
  }
  delay(300);
  // ανάποδη περιστροφή για απελευθέρωση του διακόπτη
  digitalWrite(dirPin, HIGH);
  for(int i=0; i<20; i++)
  {
    digitalWrite(stepPin, HIGH);      // περιστροφή κατά ένα βήμα
    delayMicroseconds(stepperSpeed);
    digitalWrite(stepPin, LOW);
    delayMicroseconds(800);
  }

  // αρχικοποίηση αισθητήρα BME
  Serial.println("BME280 test");
  bool status;
  status = bme.begin();
  if (!status)
  {
    Serial.println("Could not find a valid BME280 sensor, check wiring!");
    lcd.setCursor(0, 0);
    lcd.print("BME error.......");
    while (1);  // ατέρμων βρόχος - τέλος προγράμματος
  }
}

void loop()
{
  readSensors();      // διάβασμα αισθητήρων

  printValues();      // εμφάνιση τιμών αισθητήρων στο serial monitor

  screen1();          // εμφάνιση τιμών αισθητήρων στην οθόνη LCD
  delay(2000);
  screen2();
  delay(2000);
  screen3();
  delay(2000);

  checkConditions();  // έλεγχος συνθηκών
}

// υποπρόγραμμα για διάβασμα αισθητήρων
void readSensors()
{
  // διάβασμα αισθητήρα BME θερμοκρασίας, υγρασίας αέρα και πίεσης
  temp = bme.readTemperature();
  hum = bme.readHumidity();
  pressure = bme.readPressure() / 100.0F;

  // διάβασμα υγρασίας εδάφους από τους 2 αισθητήρες
  value = analogRead(hygrometer);
  value = constrain(value,400,1023);
  // μετατροπή υγρασίας σε ποσοστό
  value = map(value,400,1023,100,0);

  value2 = analogRead(hygrometer2);
  value2 = constrain(value2,400,1023);
  // μετατροπή υγρασίας σε ποσοστό
  value2 = map(value2,400,1023,100,0);

  // διάβασμα αισθητήρα μεθανίου
  methValue = analogRead(MQ4pin);
}

// 1η οθόνη: εμφάνιση υγρασίας εδάφους
void screen1()
{
  lcd.clear();
  lcd.setCursor(0, 0); 
  lcd.print("H1: ");
  lcd.print(value);
  lcd.print("%");
  lcd.print(" - H2: ");
  lcd.print(value2);
  lcd.print("%");
  lcd.setCursor(0, 1); 
  lcd.print("AvgHum: ");
  lcd.print((value+value2)/2);
}

// 2η οθόνη: εμφάνιση θερμοκρασίας - ατμοσφαιρικής πίεσης
void screen2()
{
  lcd.clear();
  lcd.setCursor(0, 0); 
  lcd.print("Temp: ");
  lcd.print(temp);
  lcd.setCursor(0, 1); 
  lcd.print("Pressure: ");
  lcd.print(pressure);
}

// 3η οθόνη: εμφάνιση μεθανίου - υγρασίας αέρα
void screen3()
{
  lcd.clear();
  lcd.setCursor(0, 0); 
  lcd.print("Methane: ");
  lcd.print(methValue);
  lcd.setCursor(0, 1); 
  lcd.print("AirHum: ");
  lcd.print(hum);
}

// υποπρόγραμμα ελέγχου των τιμών των αισθητήρων και λήψης απόφασης για τις αντίστοιχες ενέργειες
void checkConditions()
{
  // έλεγχος αν η υγρασία αέρα είναι > 60% 
  lcd.clear();
  if( hum > 60 )
  {
    lcd.setCursor(0, 0);
    lcd.print("POLLH YGRASIA   ");
    lcd.setCursor(0, 1);
    lcd.print("ANEMISTHRAS ON  ");
    digitalWrite(fanPin, LOW);    // ενεργοποίηση ανεμιστήρα
  }
  else
  {
    lcd.setCursor(0, 0);
    lcd.print("LIGH YGRASIA");
    lcd.setCursor(0, 1);
    lcd.print("ANEMISTHRAS OFF ");    
    digitalWrite(fanPin, HIGH);   // απενεργοποίηση ανεμιστήρα
  }
  delay(2000);

  // έλεγχος αν η υγρασία εδάφους είναι < 40%
  lcd.clear();
  if( (value + value2)/2 < 40 )
  {
    lcd.setCursor(0, 0);
    lcd.print("THELEI NERO     ");
    lcd.setCursor(0, 1);
    lcd.print("ANTLIA ANOIKTH  ");
    digitalWrite(motorPin, LOW);    // ενεργοποίηση αντλίας
  }
  else
  {
    lcd.setCursor(0, 0);
    lcd.print("EXEI ARKETO NERO");
    lcd.setCursor(0, 1);
    lcd.print("ANTLIA KLEISTH  ");
    digitalWrite(motorPin, HIGH);   // απενεργοποίηση αντλίας
  }
  delay(2000);

  // ελεγχος για το μεθάνιο
  lcd.clear();
  if( methValue > 650 )
  {
    lcd.setCursor(0, 0);
    lcd.print("METHANIO ARKETO ");
    delay(1000);
    peristrofiKadou();    // αναποδογύρισμα κάδου
  }
  else
  {
    delay(1000);
  }
}

// υποπρόγραμμα για αναποδογύρισμα κάδου
void peristrofiKadou()
{
  lcd.clear();
  lcd.setCursor(0, 0);
  lcd.print("PERISTROFI KADOU");
  lcd.setCursor(0, 1);
  if( DexiaAristera )
    lcd.print("ARISTERA        ");
  else
    lcd.print("DEXIA           ");

  // ορισμός κατεύθυνσης περιστροφής
  digitalWrite(dirPin, DexiaAristera);
  // περιστροφή κατά "strofi" βήματα
  for(int x = 0; x < strofi; x++)
  {
    digitalWrite(stepPin, HIGH);
    delayMicroseconds(stepperSpeed);
    digitalWrite(stepPin, LOW);
    delayMicroseconds(800);
  }
  DexiaAristera = !DexiaAristera; // αλλαγή κατεύθυνσης περιστροφής
}

// υποπρόγραμμα εμφάνισης τιμών στη σειριακή οθόνη
void printValues()
{
  Serial.println("SENSOR VALUES");
  Serial.println("--------------------------");

  Serial.print("Temperature = ");
  Serial.print(temp);
  Serial.println(" *C");
  
  Serial.print("Pressure = ");
  Serial.print(pressure);
  Serial.println(" hPa");
  
  Serial.print("Air Humidity = ");
  Serial.print(hum);
  Serial.println(" %");

  Serial.print("Soil Humidity 1 = ");
  Serial.print(value);
  Serial.println(" %");

  Serial.print("Soil Humidity 2 = ");
  Serial.print(value2);
  Serial.println(" %");

  Serial.print("Methane = ");
  Serial.println(methValue);
  Serial.println();
}
